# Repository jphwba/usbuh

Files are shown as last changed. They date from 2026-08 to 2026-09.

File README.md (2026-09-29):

# Usbuh

This is a USB Hub that features USB-C input, an Auxilary Port with Audio in and out, three USB-A 2.0 ports, two USB-C 2.0 ports and a micro SD Card slot. The main USB hub controllers are two FE1.1s's, a GL823K for the micro-sd controller, an AMS1117-3.3 to step down 5v connections into 3v3 and a PCM2902E for the audio controller. I made this because on my desk the area where my PC is requires the top IO to be blocked which had all of these ports and there was no space to run a cable it was a very tight gap so my current solution is running a $5 temu adapter which goes through a USB-C to USB-A adapter ($0.30 from temu) and a USB1.0 extension cable, so my devices do run pretty slow. So I decided to make this. SInce I'm not very experienced with KiCad and with PCB's and everything, I found USB3.0 a bit more complex and I realised that my design was USB2.0 only too far into the project so I just stuck with 2.0. I also decided later in the project that I wanted an aux port since my headset has an audio/mic combo port and my PC only has split and the adapter I used doesn't work. 

## Printing Notice
Please print 5 connector brakets as there is only 1 in the step file.

## Assembly

The USB Hub has a pretty simple assembly requiring only 4 screws. First in the base plate 4 heatset inserts (M2x3.2mm) go into the standoffs. Then the pcb just goes on top and is screwed in. After this, the walls are placed just on top of the base plate and is attatched with connector brackets I made which go along the sides. Then the top plate just props ontop of the walls and then the front cover is attatched by just pressing it into the front of the assembly. 

## Images

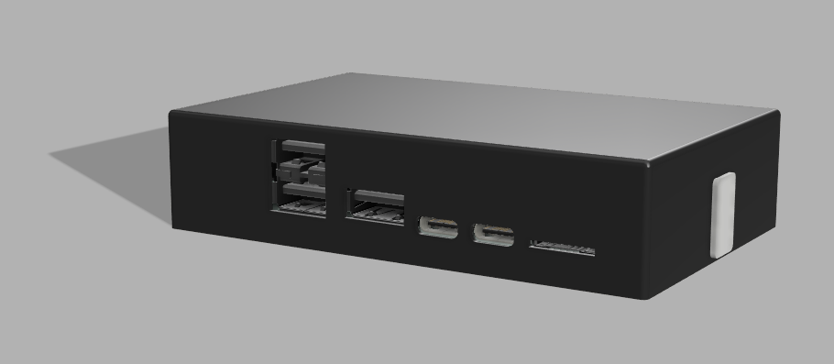
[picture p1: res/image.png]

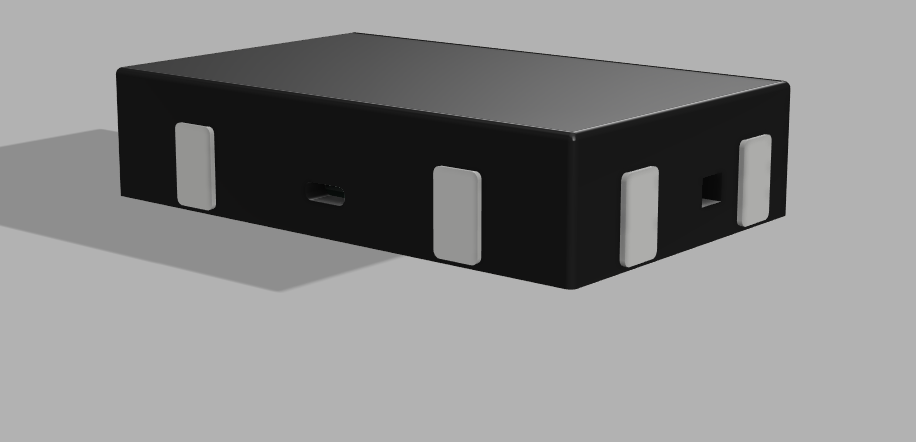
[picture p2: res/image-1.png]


### PCB
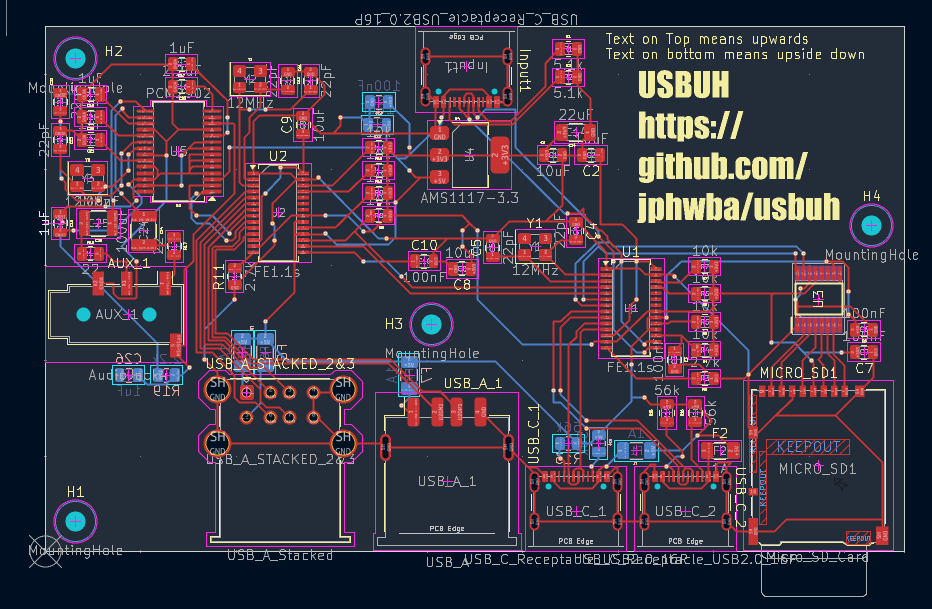
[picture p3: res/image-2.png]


### PCB Render

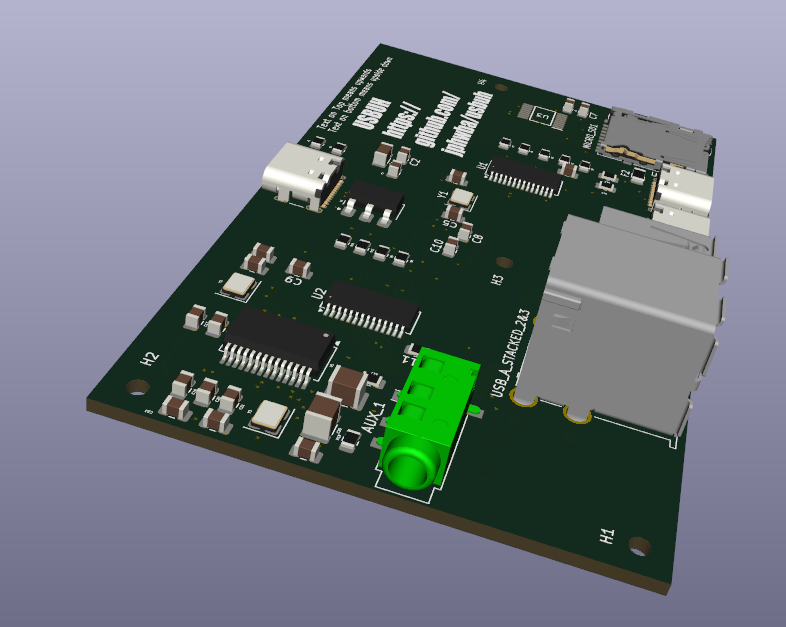
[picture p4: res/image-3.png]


### Schematic

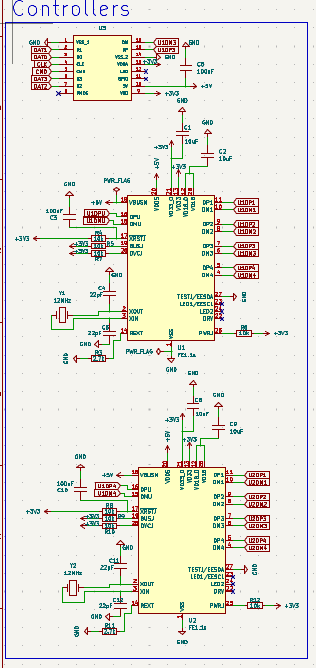
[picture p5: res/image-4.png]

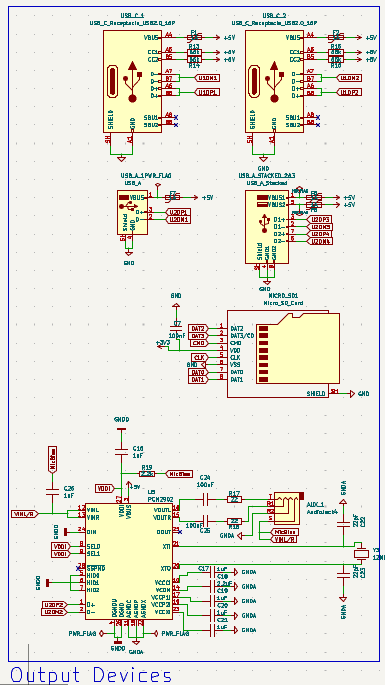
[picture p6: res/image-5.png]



### PCB Order
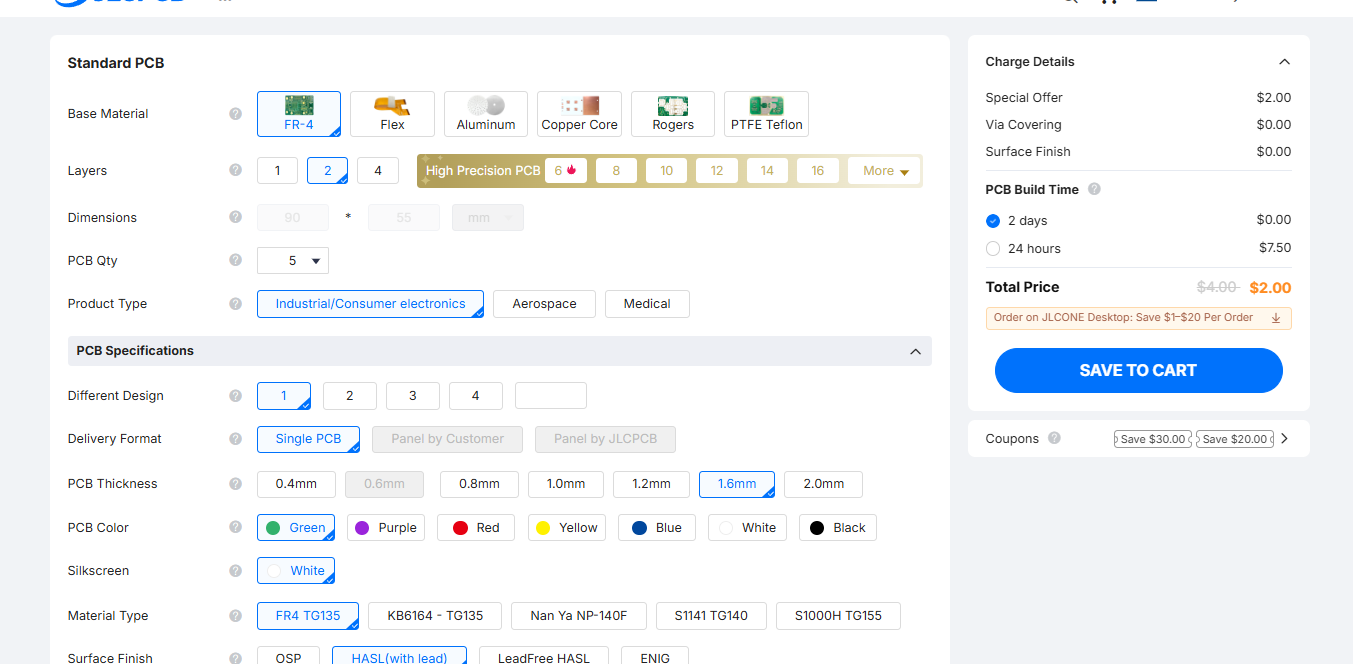
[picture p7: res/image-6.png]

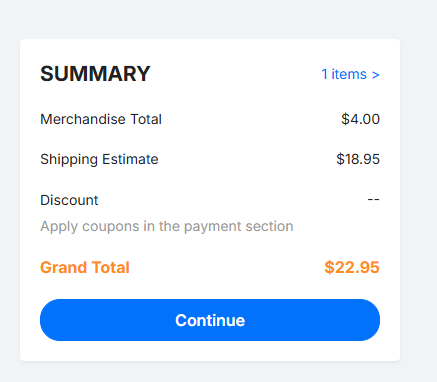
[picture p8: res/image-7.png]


## Bill of Materials: PLEASE NOTE ALL PRICES ARE IN AUSTRALIAN DOLLARS
|Reference                |Qty|Value                      |Footprint                                                            |Datasheet                                                                        |Item Name                                                                                                                       |Qty|Variation                                  |Price (AUD)|Shipping Fee (If Applicable)|Reference                                                                                                                                                                                                                                                                                                                                                                                                                                                                                                                                                                                                                                                                                                                                                                      |
|Reference                |Qty|Value                      |Footprint                                                            |Datasheet                                                                        |Item Name              |Qty|Variation                                                                                      |Price (USD)|Shipping Fee (If Applicable)|Reference                                                         |
|-------------------------|---|---------------------------|---------------------------------------------------------------------|---------------------------------------------------------------------------------|-----------------------|---|-----------------------------------------------------------------------------------------------|-----------|----------------------------|------------------------------------------------------------------|
|AUX_1                    |1  |AudioJack4                 |Connector_Audio:Jack_3.5mm_PJ320D_Horizontal                         |                                                                                 |PJ-320D                |10 |3.5mm Headphone Jack 0.5A 30V Surface Mount                                                    | $0.51     |                            |https://www.lcsc.com/product-detail/C431535.html                  |
|C1,C2,C8,C9,C13          |5  |10uF                       |Capacitor_SMD:C_0805_2012Metric                                      |                                                                                 |CS2012X7R106M100NRE    |10 |10uF �20% 10V Ceramic Capacitor X7R 0805                                                       | $0.81     |                            |https://www.lcsc.com/product-detail/C5189822.html                 |
|C3,C6,C7,C10,C15         |5  |100nF                      |Capacitor_SMD:C_0805_2012Metric                                      |                                                                                 |CL21B104KBCNNNC        |20 |100nF �10% 50V Ceramic Capacitor X7R 0805                                                      | $0.30     |                            |https://www.lcsc.com/product-detail/C1711.html                    |
|C4,C5,C11,C12,C22,C23    |6  |22pF                       |Capacitor_SMD:C_0805_2012Metric                                      |                                                                                 |CL21C220JBANNNC        |50 |22pF �5% 50V Ceramic Capacitor C0G 0805                                                        | $0.62     |                            |https://www.lcsc.com/product-detail/C1804.html                    |
|C14                      |1  |22uF                       |Capacitor_SMD:C_1206_3216Metric                                      |                                                                                 |CL21A226MOQNNNE        |10 |22uF �20% 16V Ceramic Capacitor X5R 0805                                                       | $1.06     |                            |https://www.lcsc.com/product-detail/C98190.html                   |
|C16,C17,C19,C20,C21,C26  |6  |1uF                        |Capacitor_SMD:C_0805_2012Metric                                      |                                                                                 |CL21B105KAFNNNE        |10 |1uF �10% 25V Ceramic Capacitor X7R 0805                                                        | $0.41     |                            |https://www.lcsc.com/product-detail/C116352.html                  |
|C18                      |1  |2.2uF                      |Capacitor_SMD:C_0805_2012Metric                                      |                                                                                 |CL21A225KBQNNNE        |10 |2.2uF �10% 50V Ceramic Capacitor X5R 0805                                                      | $0.54     |                            |https://www.lcsc.com/product-detail/C377773.html                  |
|C24,C25                  |2  |100uF                      |Capacitor_SMD:C_1210_3225Metric                                      |                                                                                 |CL21A107MQYNNWE        |4  |100uF �20% 6.3V Ceramic Capacitor X5R 0805                                                     | $2.95     |                            |https://www.lcsc.com/product-detail/C6882730.html                 |
|F1,F2,F5,F6,F7           |5  |1A                         |Fuse:Fuse_1206_3216Metric                                            |                                                                                 |BSMD1206-100-30V       |10 |Polymeric PTC Resettable Fuse 30V 1A Surface Mount 1206                                        | $1.01     |                            |https://www.lcsc.com/product-detail/C5358568.html                 |
|Input1,USB_C_1,USB_C_2   |3  |USB_C_Receptacle_USB2.0_16P|Connector_USB:USB_C_Receptacle_GCT_USB4105-xx-A_16P_TopMnt_Horizontal|https://www.usb.org/sites/default/files/documents/usb_type-c.zip                 |USB4105-GF-A-060       |3  |USB 2.0 1 12P -40?~+85? Surface Mount, Right Angle SMD USB, DVI, HDMI Connector Assemblies RoHS| $4.42     |                            |https://www.lcsc.com/product-detail/C3025063.html                 |
|MICRO_SD1                |1  |Micro_SD_Card              |Connector_Card:microSD_HC_Hirose_DM3AT-SF-PEJM5                      |https://www.we-online.com/components/products/datasheet/693072010801.pdf         |DM3AT-SF-PEJM5         |1  |Micro SD card (TF card) Connector and Ejector Push-Push Surface Mount                          | $1.40     |                            |https://www.lcsc.com/product-detail/C114218.html                  |
|R1,R2                    |2  |5.1k                       |Resistor_SMD:R_0805_2012Metric                                       |                                                                                 |0805W8F5101T5E         |100|5.1k? �1% 125mW 0805 Thick Film Resistor                                                       | $0.53     |                            |https://www.lcsc.com/product-detail/C27834.html                   |
|R3,R11                   |2  |2.7k                       |Resistor_SMD:R_0805_2012Metric                                       |                                                                                 |FRC0805J272 TS         |100|2.7k? �5% 125mW 0805 Thick Film Resistor                                                       | $0.32     |                            |https://www.lcsc.com/product-detail/C2907305.html                 |
|R4,R5,R6,R7,R8,R9,R10,R12|8  |10k                        |Resistor_SMD:R_0805_2012Metric                                       |                                                                                 |FRC0805F1002TS         |100|10k? �1% 125mW 0805 Thick Film Resistor                                                        | $0.34     |                            |https://www.lcsc.com/product-detail/C2907219.html                 |
|R13,R14,R15,R16          |4  |56k                        |Resistor_SMD:R_0805_2012Metric                                       |                                                                                 |0805W8F5602T5E         |100|56k? �1% 125mW 0805 Thick Film Resistor                                                        | $0.30     |                            |https://www.lcsc.com/product-detail/C17756.html                   |
|R17,R18                  |2  |22                         |Resistor_SMD:R_0805_2012Metric                                       |                                                                                 |FRC0805J220 TS         |100|22? �5% 125mW 0805 Thick Film Resistor                                                         | $0.33     |                            |https://www.lcsc.com/product-detail/C2907310.html                 |
|R19                      |1  |2.2k                       |Resistor_SMD:R_0805_2012Metric                                       |                                                                                 |0805W8F2201T5E         |100|2.2k? �1% 125mW 0805 Thick Film Resistor                                                       | $0.44     |                            |https://www.lcsc.com/product-detail/C17520.html                   |
|U1,U2                    |2  |FE1.1s                     |Package_SO:SSOP-28_3.9x9.9mm_P0.635mm                                |https://cdn-shop.adafruit.com/product-files/2991/FE1.1s+Data+Sheet+(Rev.+1.0).pdf|FE1.1S-BSOP28BCN       |2  |4 USB Hub 480Mbps USB 2.0 SSOP-28-150mil Interface Controllers RoHS                            | $1.39     |                            |https://www.lcsc.com/product-detail/C9359.html                    |
|U3                       |1  |GL823K                     |GL823K:SOP64P600X175-16N                                             |                                                                                 |GL823K-HCY04           |1  |USB to SD 480Mbps USB 2.0 SSOP-16-150mil Interface Controllers RoHS                            | $0.46     |                            |https://www.lcsc.com/product-detail/C284879.html                  |
|U4                       |1  |AMS1117-3.3                |Package_TO_SOT_SMD:SOT-223-3_TabPin2                                 |http://www.advanced-monolithic.com/pdf/ds1117.pdf                                |AMS1117-3.3            |5  |3.3V Positive Fixed SOT-223 Voltage Regulators - Linear, Low Drop Out (LDO) Regulators RoHS    | $1.05     |                            |https://www.lcsc.com/product-detail/C6186.html                    |
|U5                       |1  |PCM2902                    |Package_SO:SSOP-28_5.3x10.2mm_P0.65mm                                |http://www.ti.com/lit/ds/symlink/pcm2902c.pdf                                    |PCM2902CDBR            |1  |Encoder/decoder USB 8kHz~48kHz SSOP-28 CODECS RoHS                                             | $12.21    |                            |https://www.lcsc.com/product-detail/C2651869.html                 |
|USB_A_1                  |1  |USB_A                      |Connector_USB:USB_A_Receptacle_GCT_USB1046                           |                                                                                 |USB1046-GF-0190-L-B-A  |1  |USB 2.0 1 4P -40?~+85? SMD USB, DVI, HDMI Connector Assemblies RoHS                            | $1.35     |                            |https://www.lcsc.com/product-detail/C6307429.html                 |
|USB_A_STACKED_2&3        |1  |USB_A_Stacked              |Connector_USB:USB_A_Wuerth_61400826021_Horizontal_Stacked            |                                                                                 |907-111A1012D10200     |5  |USB-A (USB TYPE-A) Receptacle Connector 8 Position Through Hole                                | $0.93     |                            |https://www.lcsc.com/product-detail/C2341.html                    |
|Y1,Y2,Y3                 |3  |12MHz                      |Crystal:Crystal_SMD_3225-4Pin_3.2x2.5mm                              |                                                                                 |X322512MSB4SI          |5  |Crystal 12MHz �10ppm 20pF SMD3225-4P                                                           | $0.48     |                            |https://www.lcsc.com/product-detail/C9002.html                    |
|Heatset Inserts          |4  |M2x3.2mm                   |                                                                     |                                                                                 |M2x3.2mm heatset insert|4  |Brass Threaded Heat-Set Insert [M2x3x3.2]                                                      | $2.16     | $10.00                     |https://www.3dprintergear.com.au/m2-brass-threaded-heat-set-insert|
|PCB                      |1  |90x55                      |                                                                     |                                                                                 |JLPCB                  |   |                                                                                               | $23.00    |                            |                                                                  |
|Printing Legion          |1  |                           |                                                                     |                                                                                 |                       |   |                                                                                               | $14.00    |                            |                                                                  |
|LCSC Shipping            |   |                           |                                                                     |                                                                                 |LCSC Shipping - 4PX    |   |                                                                                               | $14.97    |                            |                                                                  |
|                         |   |                           |Total Price:                                                         |                                                                                 |                       |   |                                                                                               | $98.29    |                            |                                                                  |
|                         |   |                           |                                                                     |                                                                                 |                       |   |                                                                                               |           |                            |                                                                  |
|                         |   |                           |                                                                     |                                                                                 |                       |   |                                                                                               |           |                            |                                                                  |
|                         |   |                           |                                                                     |                                                                                 |                       |   |                                                                                               |           |                            |                                                                  |

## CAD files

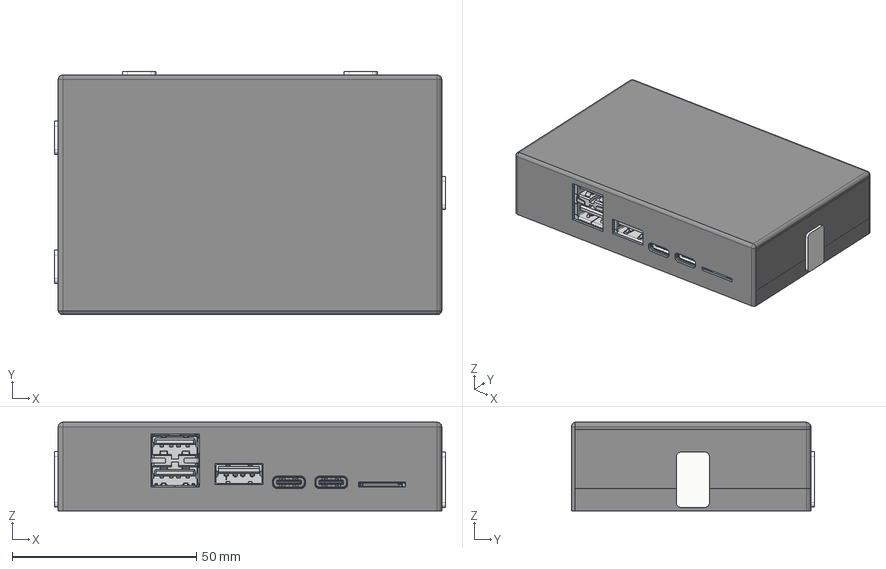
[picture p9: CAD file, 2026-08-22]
CAD/Assembly.step
106.0 x 66.0 x 24.0 mm
R_0805_2012Metric_1 x 19
C_0805_2012Metric_1 x 23
C_1206_3216Metric_1
33m8367_5787745-2
SOT-223_1
SSOP-28_5.3x10.2mm_P0.65mm_1
SSOP-28_3.9x9.9mm_P0.635mm_1 x 2
Crystal_SMD_3225-4Pin_3.2x2.5mm_1 x 3
C_1210_3225Metric_1 x 2
USB_C_Receptacle_16P_TopMnt_Horizontal_GCT_USB4105-xx-A x 3
microSD_HC_Hirose_DM3AT-SF-PEJM5_1
72w2540_292303-7
PJ320A
PJ320D-Pin x 3
PJ320D-Pin-B
Fuse_1206_3216Metric_1 x 5
usbuh_PCB
Base
Walls
Connector Bracket x 5
Top
Front Cover

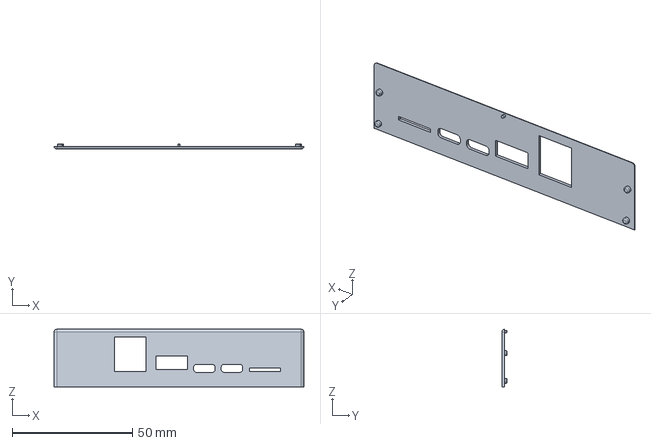
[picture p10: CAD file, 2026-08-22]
Production/Front Cover.step
104.0 x 2.20 x 24.0 mm

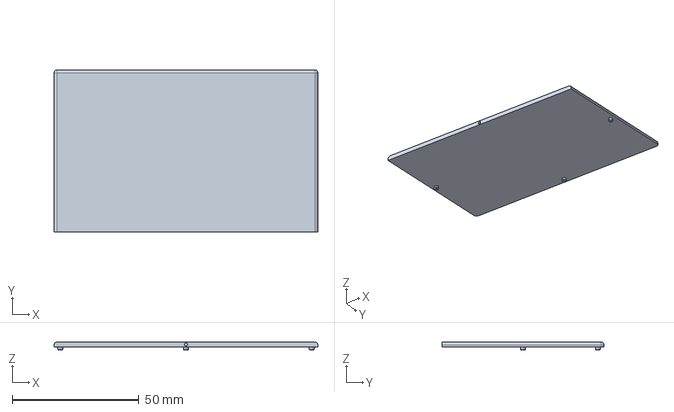
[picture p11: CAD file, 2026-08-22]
Production/Top.step
104.0 x 64.0 x 3.20 mm

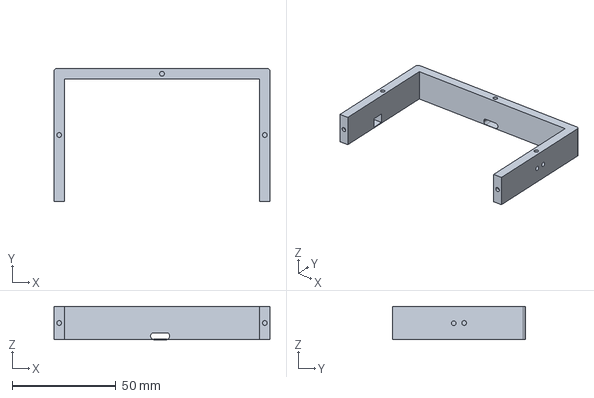
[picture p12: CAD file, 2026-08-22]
Production/Walls.step
104.0 x 64.0 x 16.0 mm

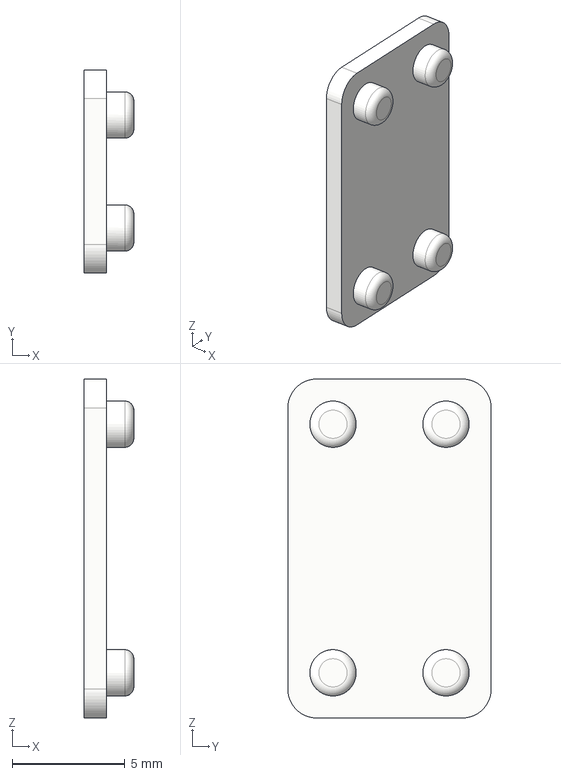
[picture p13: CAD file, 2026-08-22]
Production/Connector Bracket.step
2.20 x 9.00 x 15.0 mm

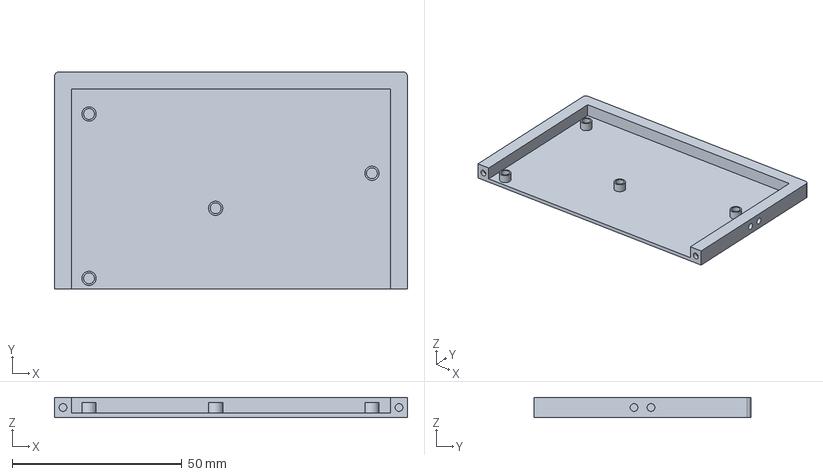
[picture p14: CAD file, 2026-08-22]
Production/Base.step
104.0 x 64.0 x 6.00 mm

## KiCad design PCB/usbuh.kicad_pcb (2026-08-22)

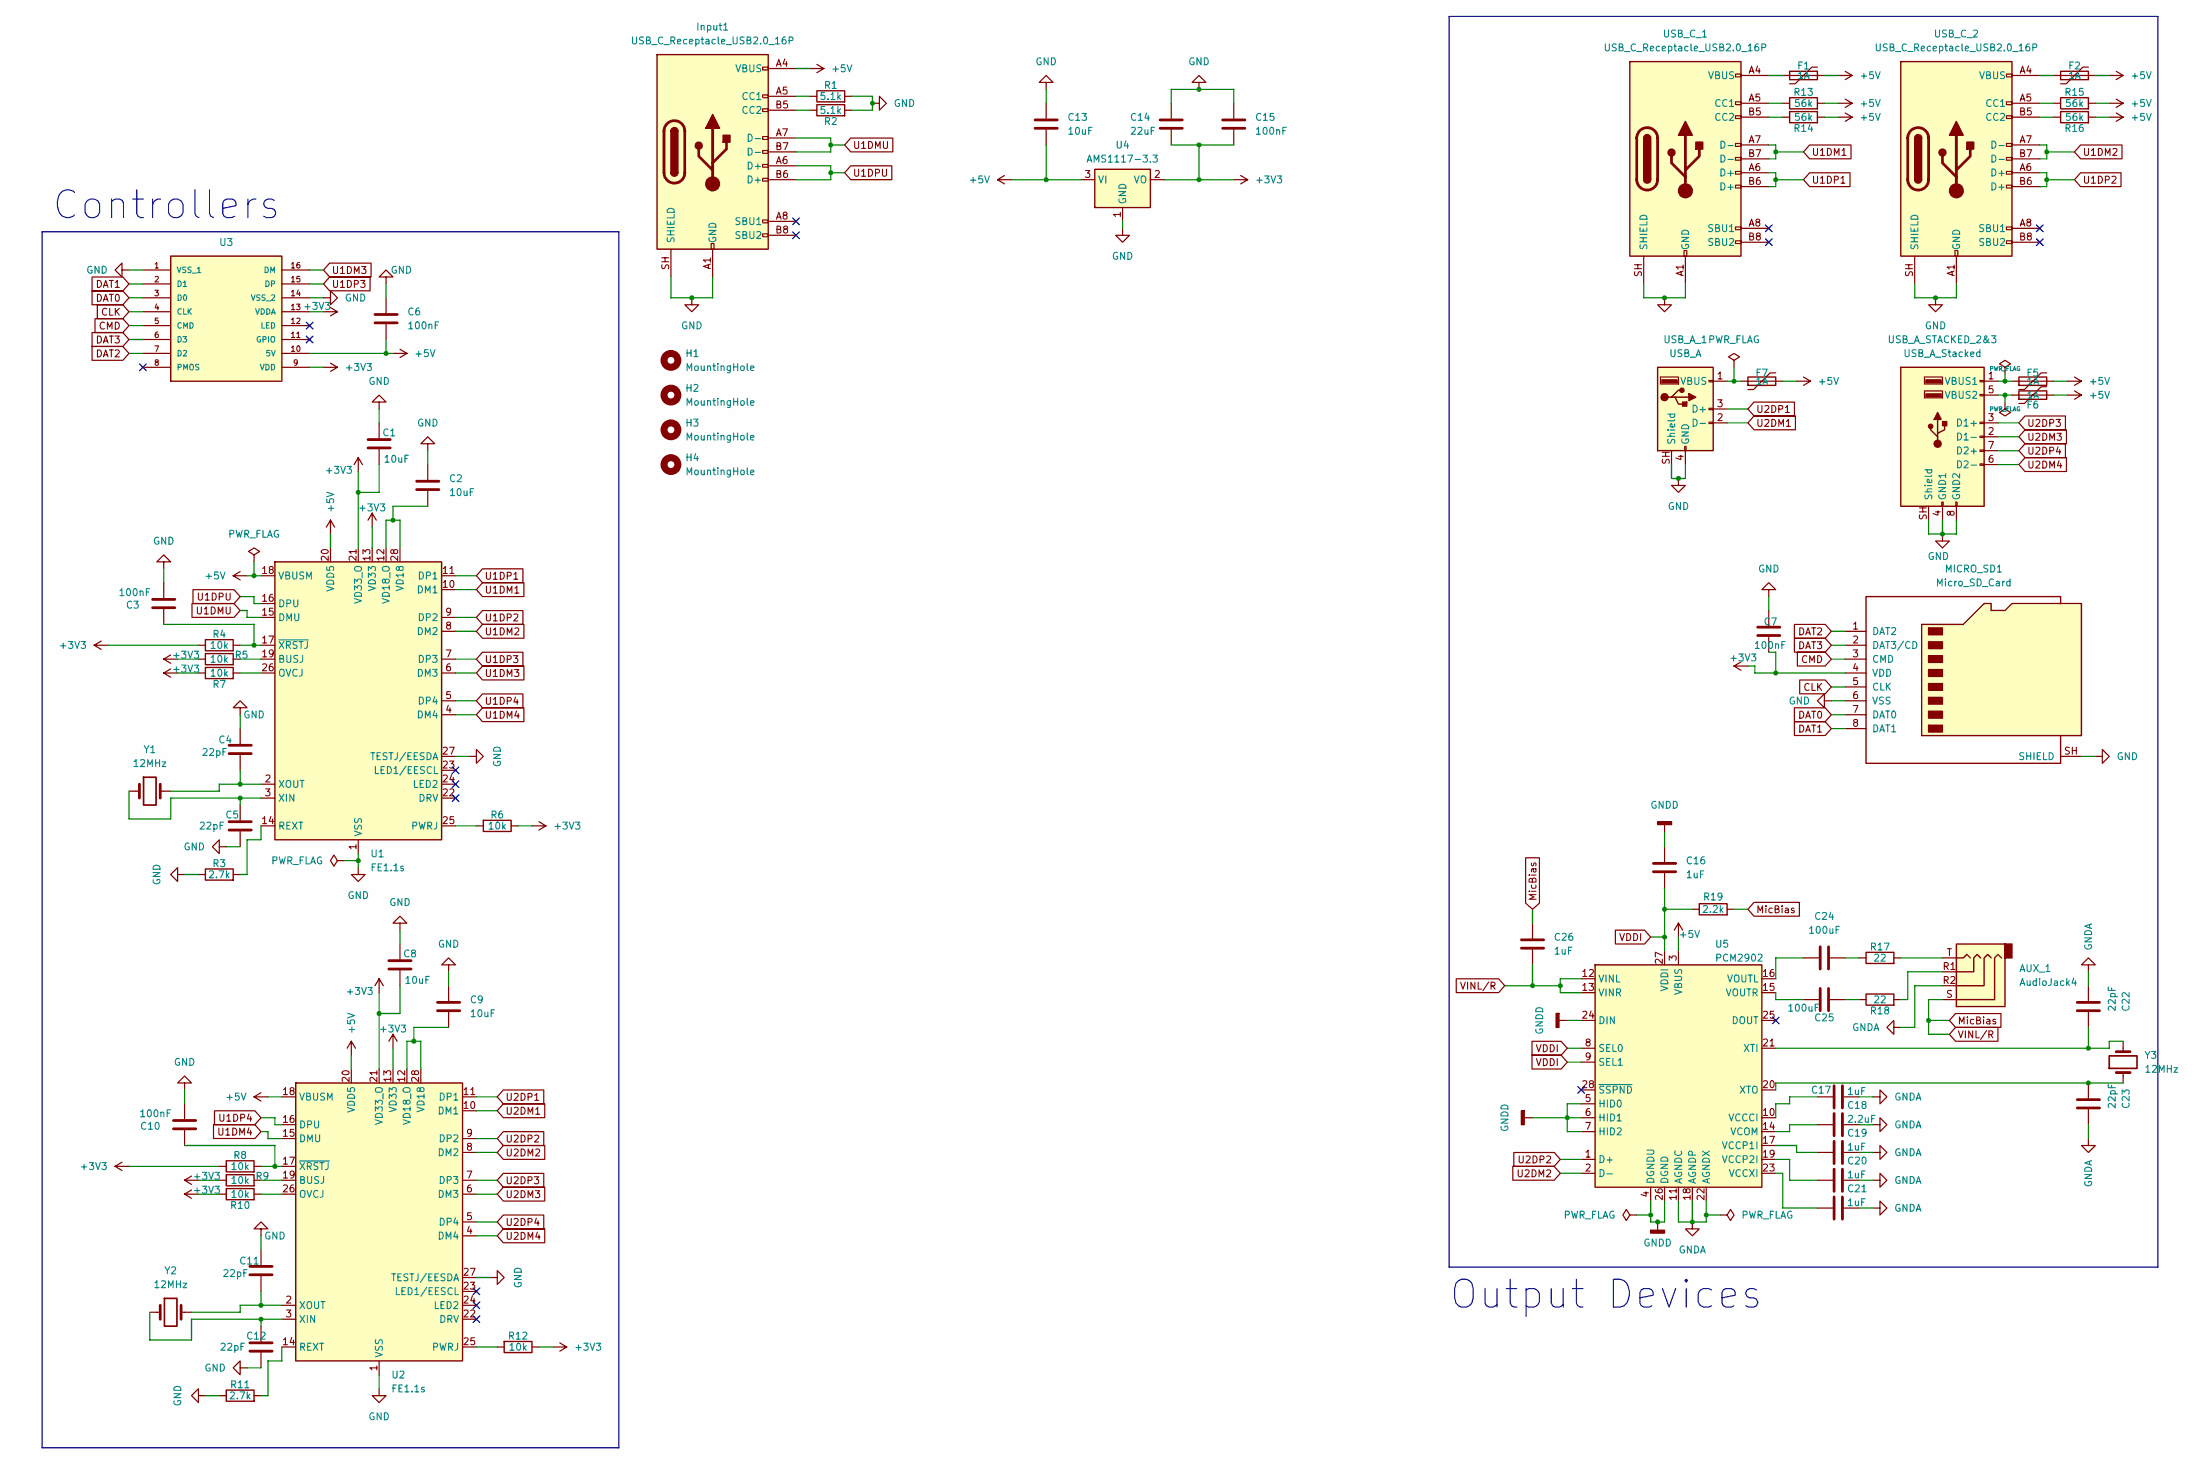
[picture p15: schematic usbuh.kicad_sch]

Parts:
AUX_1: AudioJack4; Jack_3.5mm_PJ320D_Horizontal
C1, C2, C8, C9, C13: 10uF; C_0805_2012Metric
C3, C6, C7, C10, C15: 100nF; C_0805_2012Metric
C4, C5, C11, C12, C22, C23: 22pF; C_0805_2012Metric
C14: 22uF; C_1206_3216Metric
C16, C17, C19, C20, C21, C26: 1uF; C_0805_2012Metric
C18: 2.2uF; C_0805_2012Metric
C24, C25: 100uF; C_1210_3225Metric
F1, F2, F5, F6, F7: 1A; Fuse_1206_3216Metric
H1, H2, H3, H4: MountingHole; MountingHole_2.1mm
Input1: USB_C_Receptacle_USB2.0_16P; USB_C_Receptacle_GCT_USB4105-xx-A_16P_TopMnt_Horizontal
MICRO_SD1: Micro_SD_Card; microSD_HC_Hirose_DM3AT-SF-PEJM5
R1, R2: 5.1k; R_0805_2012Metric
R3, R11: 2.7k; R_0805_2012Metric
R4, R5, R6, R7, R8, R9, R10, R12: 10k; R_0805_2012Metric
R13, R14, R15, R16: 56k; R_0805_2012Metric
R17, R18: 22; R_0805_2012Metric
R19: 2.2k; R_0805_2012Metric
U1, U2: FE1.1s; SSOP-28_3.9x9.9mm_P0.635mm
U3: SOP64P600X175-16N; MANUFACTURER_PART_NUMBER GL823K
U4: AMS1117-3.3; SOT-223-3_TabPin2
U5: PCM2902; SSOP-28_5.3x10.2mm_P0.65mm
USB_A_1: USB_A; USB_A_Receptacle_GCT_USB1046
USB_A_STACKED_2&3: USB_A_Stacked; USB_A_Wuerth_61400826021_Horizontal_Stacked
USB_C_1, USB_C_2: USB_C_Receptacle_USB2.0_16P; USB_C_Receptacle_GCT_USB4105-xx-A_16P_TopMnt_Horizontal
Y1, Y2, Y3: 12MHz; Crystal_SMD_3225-4Pin_3.2x2.5mm

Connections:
+3V3: C1.1, C7.2, C8.1, C14.2, C15.2, MICRO_SD1.4 (VDD), R4.1, R5.1, R6.1, R7.1, R8.1, R9.1, R10.1, R12.1, U1.13 (VD33), U1.21 (VD33_O), U2.13 (VD33), U2.21 (VD33_O), U3.9 (VDD), U3.13 (VDDA), U4.2 (VO)
+5V: C6.2, C13.2, F1.2, F2.2, F5.2, F6.2, F7.2, Input1.A4 (VBUS), Input1.A9 (VBUS), Input1.B4 (VBUS), Input1.B9 (VBUS), R13.2, R14.2, R15.2, R16.2, U1.18 (VBUSM), U1.20 (VDD5), U2.18 (VBUSM), U2.20 (VDD5), U3.10 (5V), U4.3 (VI), U5.3 (VBUS)
CLK: MICRO_SD1.5 (CLK), U3.4 (CLK)
CMD: MICRO_SD1.3 (CMD), U3.5 (CMD)
DAT0: MICRO_SD1.7 (DAT0), U3.3 (D0)
DAT1: MICRO_SD1.8 (DAT1), U3.2 (D1)
DAT2: MICRO_SD1.1 (DAT2), U3.7 (D2)
DAT3: MICRO_SD1.2 (DAT3/CD), U3.6 (D3)
GND: C1.2, C2.2, C3.2, C4.1, C5.2, C6.1, C7.1, C8.2, C9.2, C10.2, C11.1, C12.2, C13.1, C14.1, C15.1, Input1.A1 (GND), Input1.A12 (GND), Input1.B1 (GND), Input1.B12 (GND), Input1.SH (SHIELD), MICRO_SD1.6 (VSS), MICRO_SD1.SH (SHIELD), R1.2, R2.2, R3.1, R11.1, U1.1 (VSS), U1.27 (TESTJ/EESDA), U2.1 (VSS), U2.27 (TESTJ/EESDA), U3.1 (VSS_1), U3.14 (VSS_2), U4.1 (GND), USB_A_1.4 (GND), USB_A_1.SH (Shield), USB_A_STACKED_2&3.4 (GND1), USB_A_STACKED_2&3.8 (GND2), USB_A_STACKED_2&3.SH (Shield), USB_C_1.A1 (GND), USB_C_1.A12 (GND), USB_C_1.B1 (GND), USB_C_1.B12 (GND), USB_C_1.SH (SHIELD), USB_C_2.A1 (GND), USB_C_2.A12 (GND), USB_C_2.B1 (GND), USB_C_2.B12 (GND), USB_C_2.SH (SHIELD)
GNDA: AUX_1.R2, C17.2, C18.2, C19.2, C20.2, C21.2, C22.2, C23.1, U5.11 (AGNDC), U5.18 (AGNDP), U5.22 (AGNDX)
GNDD: C16.2, U5.4 (DGNDU), U5.5 (HID0), U5.6 (HID1), U5.7 (HID2), U5.24 (DIN), U5.26 (DGND)
MicBias: AUX_1.S, C26.1, C26.2, R19.2, U5.12 (VINL), U5.13 (VINR)
unnamed: AUX_1.R1, R18.2
unnamed: AUX_1.T, R17.2
unnamed: C24.2, R17.1
unnamed: C25.2, R18.1
unnamed: F1.1, USB_C_1.A4 (VBUS), USB_C_1.A9 (VBUS), USB_C_1.B4 (VBUS), USB_C_1.B9 (VBUS)
unnamed: F2.1, USB_C_2.A4 (VBUS), USB_C_2.A9 (VBUS), USB_C_2.B4 (VBUS), USB_C_2.B9 (VBUS)
unnamed: Input1.A5 (CC1), R1.1
unnamed: Input1.B5 (CC2), R2.1
unnamed: R5.2, U1.19 (BUSJ)
unnamed: R7.2, U1.26 (OVCJ)
unnamed: R6.2, U1.25 (PWRJ)
unnamed: R3.2, U1.14 (REXT)
unnamed: C2.1, U1.12 (VD18_O), U1.28 (VD18)
unnamed: C5.1, U1.3 (XIN), Y1.1
unnamed: C4.2, U1.2 (XOUT), Y1.2
unnamed: C3.1, R4.2, U1.17 (~XRSTJ)
unnamed: R9.2, U2.19 (BUSJ)
unnamed: R10.2, U2.26 (OVCJ)
unnamed: R12.2, U2.25 (PWRJ)
unnamed: R11.2, U2.14 (REXT)
unnamed: C9.1, U2.12 (VD18_O), U2.28 (VD18)
unnamed: C12.1, U2.3 (XIN), Y2.1
unnamed: C11.2, U2.2 (XOUT), Y2.2
unnamed: C10.1, R8.2, U2.17 (~XRSTJ)
unnamed: C17.1, U5.10 (VCCCI)
unnamed: C19.1, U5.17 (VCCP1I)
unnamed: C20.1, U5.19 (VCCP2I)
unnamed: C21.1, U5.23 (VCCXI)
unnamed: C18.1, U5.14 (VCOM)
unnamed: C24.1, U5.16 (VOUTL)
unnamed: C25.1, U5.15 (VOUTR)
unnamed: C22.1, U5.21 (XTI), Y3.2
unnamed: C23.2, U5.20 (XTO), Y3.1
unnamed: F7.1, USB_A_1.1 (VBUS)
unnamed: F5.1, USB_A_STACKED_2&3.1 (VBUS1)
unnamed: F6.1, USB_A_STACKED_2&3.5 (VBUS2)
unnamed: R13.1, USB_C_1.A5 (CC1)
unnamed: R14.1, USB_C_1.B5 (CC2)
unnamed: R15.1, USB_C_2.A5 (CC1)
unnamed: R16.1, USB_C_2.B5 (CC2)
U1DM1: U1.10 (DM1), USB_C_1.A7 (D-), USB_C_1.B7 (D-)
U1DM2: U1.8 (DM2), USB_C_2.A7 (D-), USB_C_2.B7 (D-)
U1DM3: U1.6 (DM3), U3.16 (DM)
U1DM4: U1.4 (DM4), U2.15 (DMU)
U1DMU: Input1.A7 (D-), Input1.B7 (D-), U1.15 (DMU)
U1DP1: U1.11 (DP1), USB_C_1.A6 (D+), USB_C_1.B6 (D+)
U1DP2: U1.9 (DP2), USB_C_2.A6 (D+), USB_C_2.B6 (D+)
U1DP3: U1.7 (DP3), U3.15 (DP)
U1DP4: U1.5 (DP4), U2.16 (DPU)
U1DPU: Input1.A6 (D+), Input1.B6 (D+), U1.16 (DPU)
U2DM1: U2.10 (DM1), USB_A_1.2 (D-)
U2DM2: U2.8 (DM2), U5.2 (D-)
U2DM3: U2.6 (DM3), USB_A_STACKED_2&3.2 (D1-)
U2DM4: U2.4 (DM4), USB_A_STACKED_2&3.6 (D2-)
U2DP1: U2.11 (DP1), USB_A_1.3 (D+)
U2DP2: U2.9 (DP2), U5.1 (D+)
U2DP3: U2.7 (DP3), USB_A_STACKED_2&3.3 (D1+)
U2DP4: U2.5 (DP4), USB_A_STACKED_2&3.7 (D2+)
VDDI: C16.1, R19.1, U5.8 (SEL0), U5.9 (SEL1), U5.27 (VDDI)

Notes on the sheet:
Output Devices
Controllers

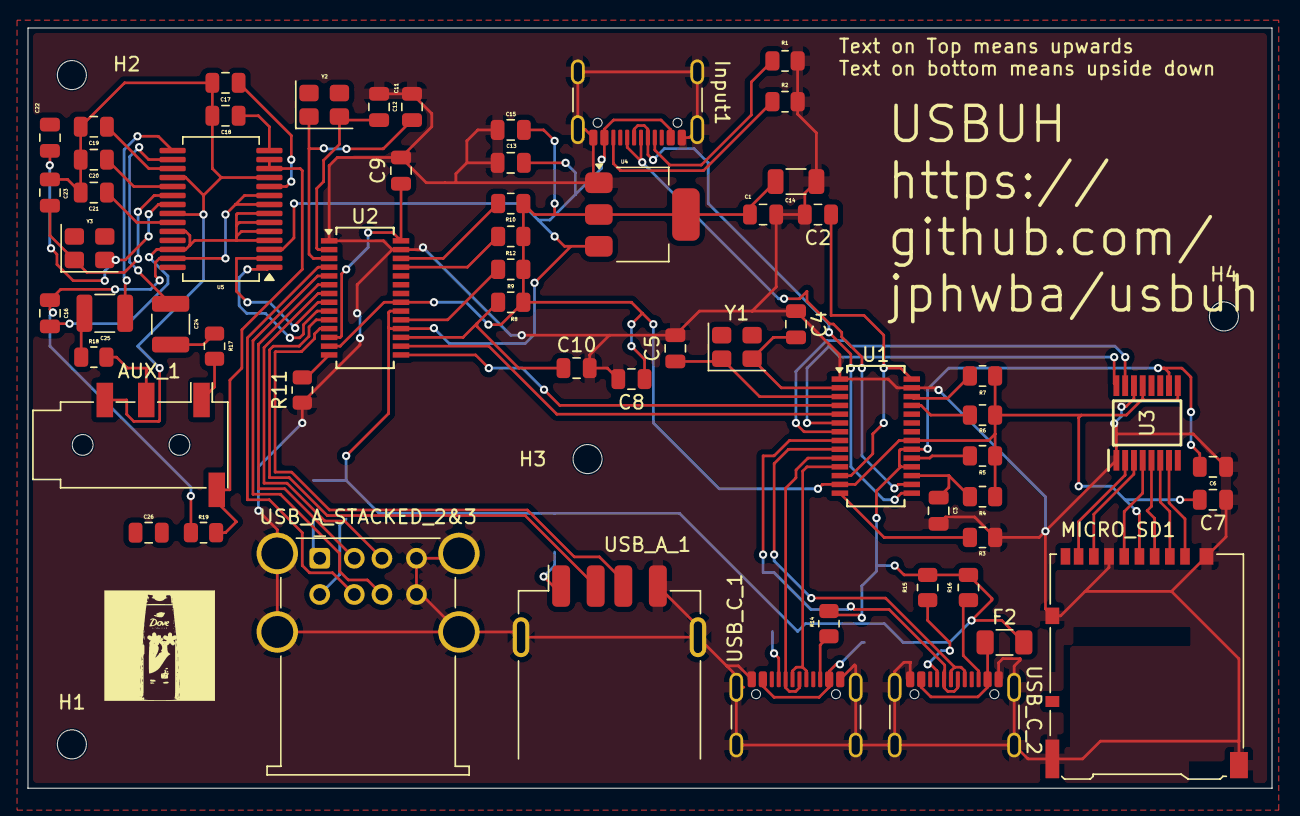
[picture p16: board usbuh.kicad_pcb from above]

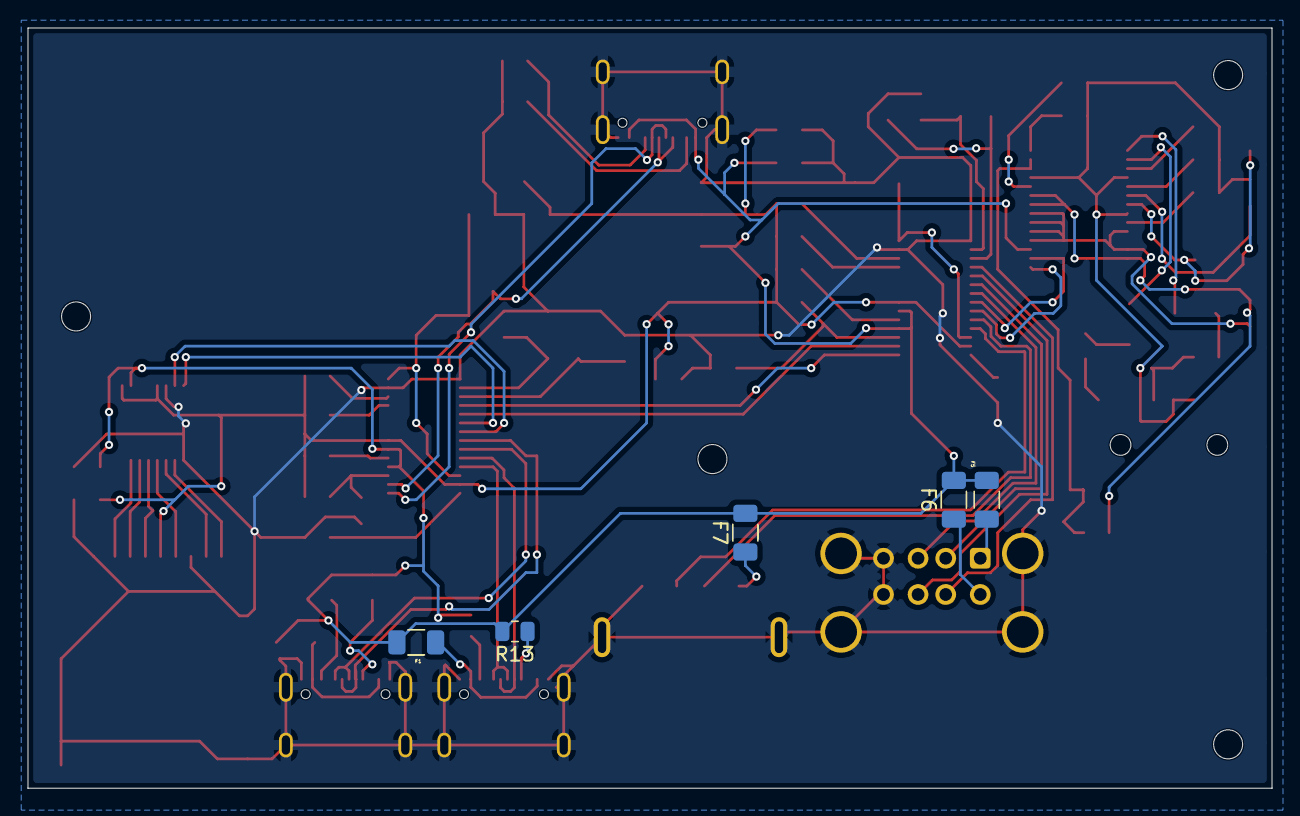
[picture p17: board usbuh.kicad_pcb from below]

Board: 2 copper layers, 90.0 x 55.0 mm, 69 parts (5 on the bottom side), 71 nets.

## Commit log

2026-08-20 Add all files
    [Assembly.step, Base.step, Connector Bracket.step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]
2026-08-22 Update cad models
    [Assembly.step, Base.step, Connector Bracket.step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]
2026-08-22 Update PCB
    [usbuh.kicad_pcb]
2026-08-22 update BOM with printing legion and new PCB prices (ong shipping is too expensive in Aus)
    [bom.csv, usbuh.csv]
2026-08-22 update readme with new pcb order ss
2026-09-29 update BOM from aliexpress to lcsc
    [bom.csv]
